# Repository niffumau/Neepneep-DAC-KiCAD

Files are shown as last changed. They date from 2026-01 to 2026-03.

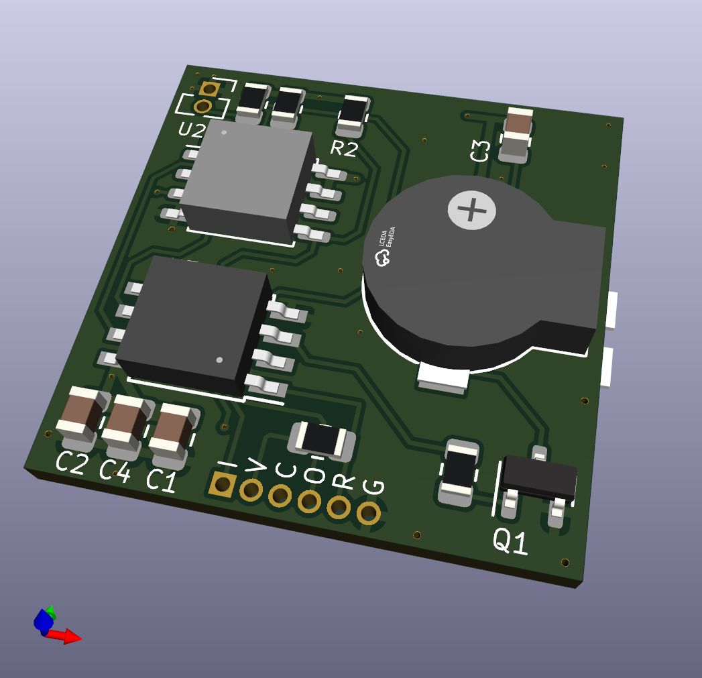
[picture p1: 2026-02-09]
V2/NeepNeep-DAC-V2.png

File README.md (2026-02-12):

# Neepneep DAC

This is the version that plays audio from a flash chip.

## V1
My original prototype, working with the Attiny85 and the winbond W25Q32 flash chip.

## V2

V2 is currently a work in progress, i'm trying bring the cost down so i'm trying to switch over to a smaller flash and move over to a different chip so this one will not program the Attiny85

I'm looking at the Attiny412 and the 8mbit version of the flash chip.

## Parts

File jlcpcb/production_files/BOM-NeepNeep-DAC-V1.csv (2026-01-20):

Comment | Designator | Footprint | LCSC
W25Q32JVSS | U2 | SOIC-8_5.23x5.23mm_P1.27mm | C179173
MMBT3904 | Q1 | SOT-23 | C20526
ATtiny85-20SU | U3 | SOIC-8W_5.3x5.3mm_P1.27mm | C31540447
YS-SBZ9032C03R16_C409828 | BUZZER1 | BUZ-SMD_FUET-9025-XXV | C409828
100nF | C4 | C_0805_2012Metric
100nF | C3 | C_0805_2012Metric
10k | R3 | R_0805_2012Metric
10k | R2 | R_0805_2012Metric
10k | R1 | R_0805_2012Metric
1N4148W | D3 | D_SOD-123
1N4148W | D2 | D_SOD-123
1N4148W | D1 | D_SOD-123
47uF | C1 | C_0805_2012Metric
10K | R6 | R_0805_2012Metric
100nF | C2 | C_0805_2012Metric
1k | R7 | R_0805_2012Metric

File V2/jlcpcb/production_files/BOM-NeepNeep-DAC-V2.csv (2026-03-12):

Comment | Designator | Footprint | LCSC
W25Q32JVSS | U2 | SOIC-8_5.23x5.23mm_P1.27mm | C179173
YS-SBZ9032C03R16_C409828 | BUZZER1 | BUZ-SMD_FUET-9025-XXV | C409828
Battery | BT1 | BatteryHolder_SMD_TAB_2032 | C964835
Conn_02x03_Odd_Even | J1 | SPI-Header_1x06_P1.27mm
Conn_01x03_Pin | J2 | UPDI PinHeader_1x03_P1.27mm_Vertical
47uF | C1 | C_0805_2012Metric
100k | R4 | R_0805_2012Metric
BSS138 | Q1 | SOT-23
10K | R6 | R_0805_2012Metric
10k | R3 | R_0805_2012Metric
10k | R2 | R_0805_2012Metric
100nF | C3 | C_0805_2012Metric
10k | R1 | R_0805_2012Metric
100nF | C4 | C_0805_2012Metric
100nF | C2 | C_0805_2012Metric
1k | R7 | R_0805_2012Metric
ATtiny412-SS | U1 | SOIC-8_3.9x4.9mm_P1.27mm

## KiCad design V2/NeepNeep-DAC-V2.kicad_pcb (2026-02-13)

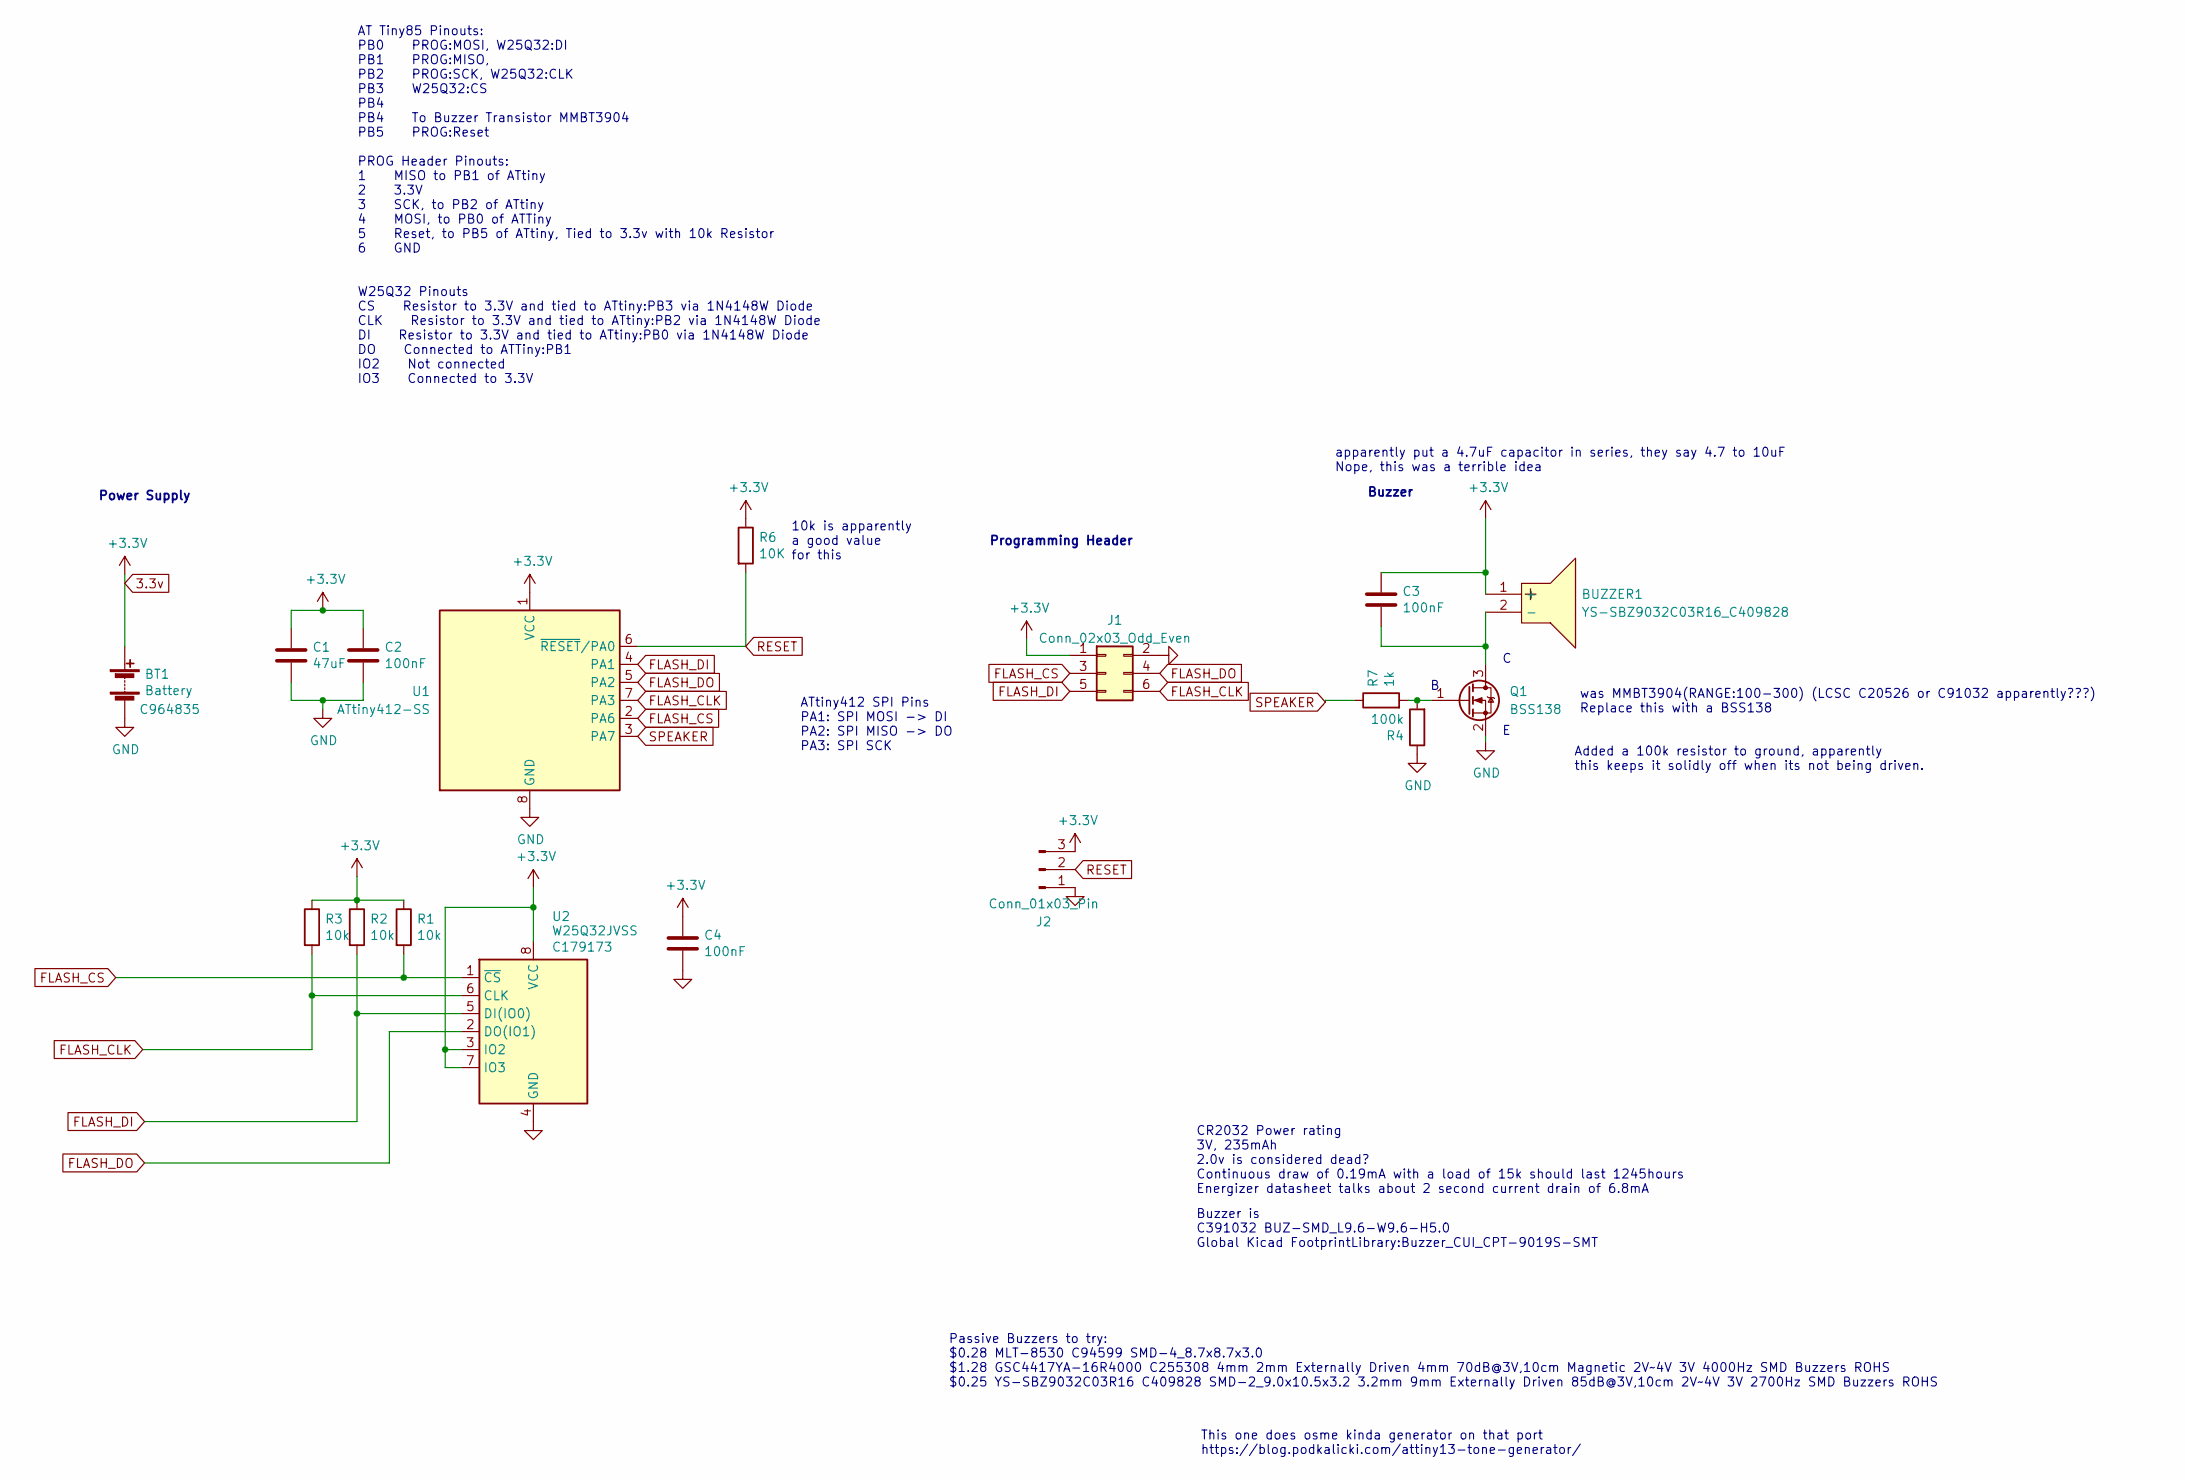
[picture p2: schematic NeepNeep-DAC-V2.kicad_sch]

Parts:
BT1: Battery; BatteryHolder_SMD_TAB_2032; LCSC C964835
BUZZER1: YS-SBZ9032C03R16_C409828; BUZ-SMD_FUET-9025-XXV; LCSC Part C409828
C1: 47uF; C_0805_2012Metric
C2, C3, C4: 100nF; C_0805_2012Metric
J1: Conn_02x03_Odd_Even; SPI-Header_1x06_P1.27mm
J2: Conn_01x03_Pin; UPDI PinHeader_1x03_P1.27mm_Vertical
Q1: BSS138; SOT-23
R1, R2, R3: 10k; R_0805_2012Metric
R4: 100k; R_0805_2012Metric
R6: 10K; R_0805_2012Metric
R7: 1k; R_0805_2012Metric
U1: ATtiny412-SS; SOIC-8_3.9x4.9mm_P1.27mm
U2: W25Q32JVSS; SOIC-8_5.23x5.23mm_P1.27mm; LCSC C179173

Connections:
3.3v: BT1.1 (+), BUZZER1.1 (+), C1.1, C2.1, C3.1, C4.1, J1.1, J2.3, R1.1, R2.1, R3.1, R6.1, U1.1 (VCC), U2.3 (IO2), U2.7 (IO3), U2.8 (VCC)
FLASH_CLK: J1.6, R3.2, U1.7 (PA3), U2.6 (CLK)
FLASH_CS: J1.3, R1.2, U1.2 (PA6), U2.1 (~CS)
FLASH_DI: J1.5, R2.2, U1.4 (PA1), U2.5 (DI(IO0))
FLASH_DO: J1.4, U1.5 (PA2), U2.2 (DO(IO1))
GND: BT1.2 (-), C1.2, C2.2, C4.2, J1.2, J2.1, Q1.2 (S), R4.1, U1.8 (GND), U2.4 (GND)
unnamed: BUZZER1.2 (-), C3.2, Q1.3 (D)
unnamed: Q1.1 (G), R4.2, R7.2
RESET: J2.2, R6.2, U1.6 (~RESET/PA0)
SPEAKER: R7.1, U1.3 (PA7)

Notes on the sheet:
apparently put a 4.7uF capacitor in series, they say 4.7 to 10uF Nope, this was a terrible idea
This one does osme kinda generator on that port https://blog.podkalicki.com/attiny13-tone-generator/
Programming Header
ATtiny412 SPI Pins PA1: SPI MOSI -> DI PA2: SPI MISO -> DO PA3: SPI SCK
Buzzer is C391032 BUZ-SMD_L9.6-W9.6-H5.0 Global Kicad FootprintLibrary:Buzzer_CUI_CPT-9019S-SMT
Added a 100k resistor to ground, apparently this keeps it solidly off when its not being driven.
Buzzer
AT Tiny85 Pinouts: PB0 PROG:MOSI, W25Q32:DI PB1 PROG:MISO, PB2 PROG:SCK, W25Q32:CLK PB3 W25Q32:CS PB4 PB4 To Buzzer Transistor MMBT3904 PB5 PROG:Reset PROG Header Pinouts: 1 MISO to PB1 of ATtiny 2 3.3V 3 SCK, to PB2 of ATtiny 4 MOSI, to PB0 of ATTiny 5 Reset, to PB5 of ATtiny, Tied to 3.3v with 10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
CR2032 Power rating 3V, 235mAh 2.0v is considered dead? Continuous draw of 0.19mA with a load of 15k should last 1245hours Energizer datasheet talks about 2 second current drain of 6.8mA
Passive Buzzers to try: $0.28 MLT-8530 C94599 SMD-4_8.7x8.7x3.0 $1.28 GSC4417YA-16R4000 C255308 4mm 2mm Externally Driven 4mm 70dB@3V,10cm Magnetic 2V~4V 3V 4000Hz SMD Buzzers ROHS $0.25 YS-SBZ9032C03R16 C409828 SMD-2_9.0x10.5x3.2 3.2mm 9mm Externally Driven 85dB@3V,10cm 2V~4V 3V 2700Hz SMD Buzzers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
Power Supply
10k is apparently a good value for this
was MMBT3904(RANGE:100-300) (LCSC C20526 or C91032 apparently???) Replace this with a BSS138

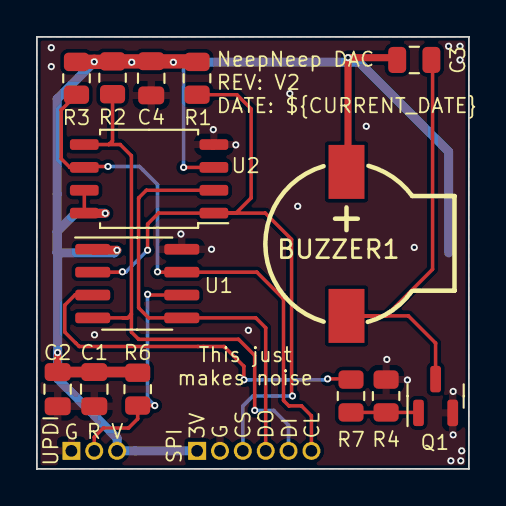
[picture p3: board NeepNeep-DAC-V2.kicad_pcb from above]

Board: 2 copper layers, 24.0 x 24.0 mm, 17 parts (1 on the bottom side), 10 nets.

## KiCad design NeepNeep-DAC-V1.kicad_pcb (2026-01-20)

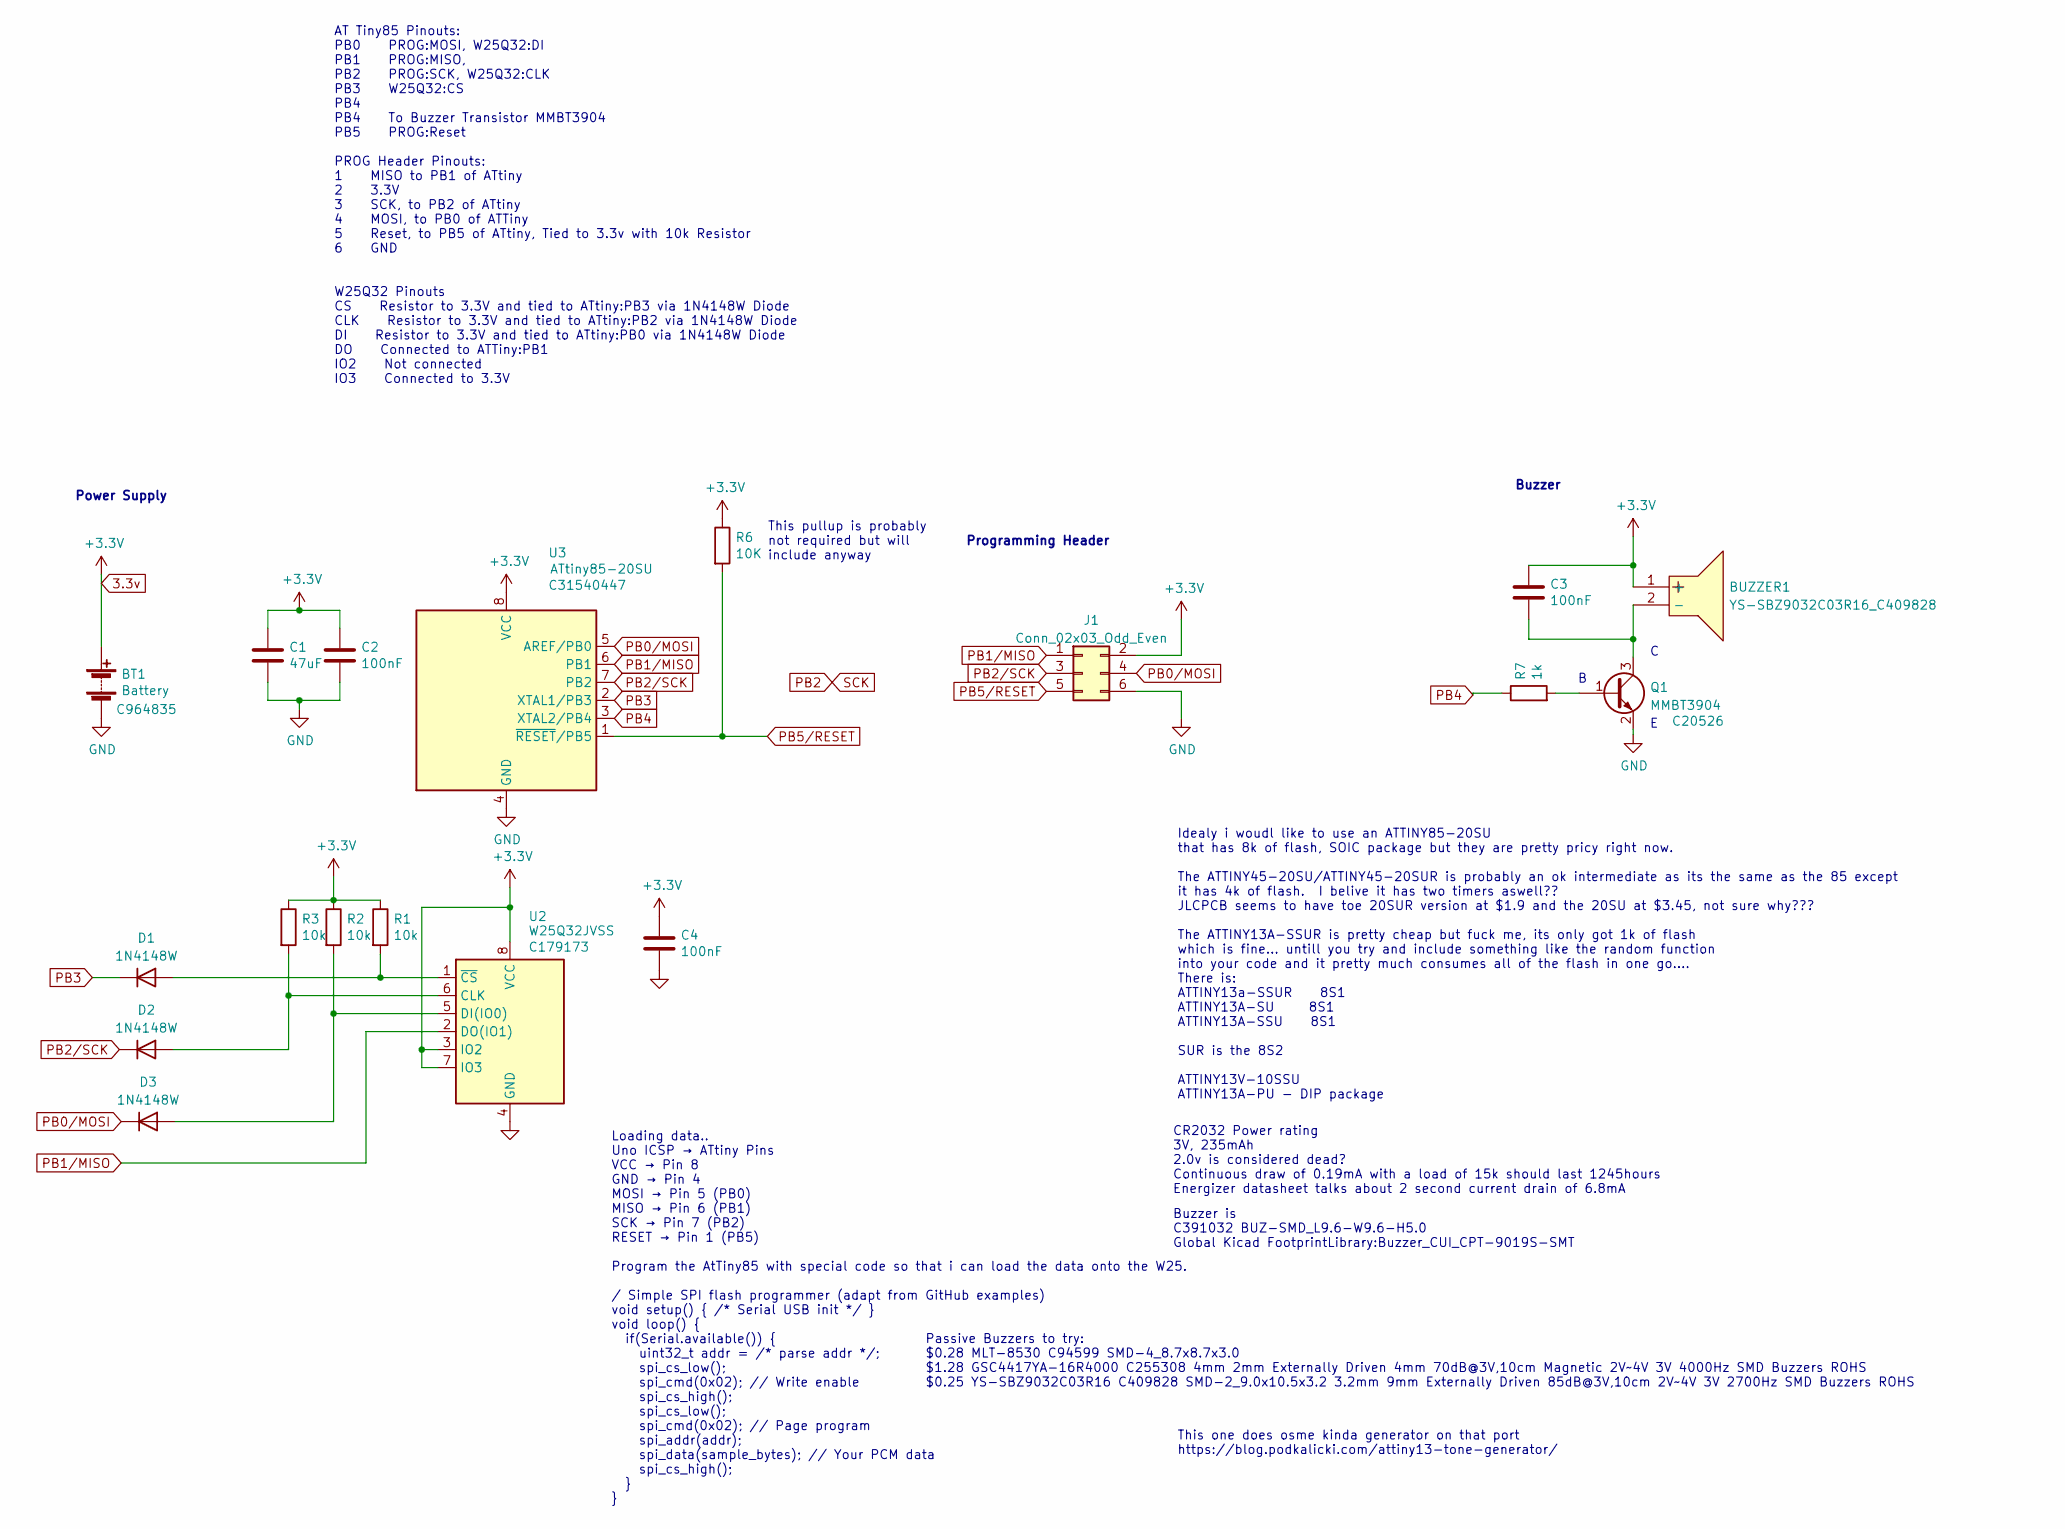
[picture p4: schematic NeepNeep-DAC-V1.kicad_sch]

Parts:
BT1: Battery; BatteryHolder_SMD_TAB_2032; LCSC C964835
BUZZER1: YS-SBZ9032C03R16_C409828; BUZ-SMD_FUET-9025-XXV; LCSC Part C409828
C1: 47uF; C_0805_2012Metric
C2, C3, C4: 100nF; C_0805_2012Metric
D1, D2, D3: 1N4148W; D_SOD-123
J1: Conn_02x03_Odd_Even; PRG-Header_1x06_P1.27mm
Q1: MMBT3904; SOT-23; LCSC C20526
R1, R2, R3: 10k; R_0805_2012Metric
R6: 10K; R_0805_2012Metric
R7: 1k; R_0805_2012Metric
U2: W25Q32JVSS; SOIC-8_5.23x5.23mm_P1.27mm; LCSC C179173
U3: ATtiny85-20SU; SOIC-8W_5.3x5.3mm_P1.27mm; LCSC C31540447

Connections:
3.3v: BT1.1 (+), BUZZER1.1 (+), C1.1, C2.1, C3.1, C4.1, J1.2, R1.1, R2.1, R3.1, R6.1, U2.3 (IO2), U2.7 (IO3), U2.8 (VCC), U3.8 (VCC)
GND: BT1.2 (-), C1.2, C2.2, C4.2, J1.6, Q1.2 (E), U2.4 (GND), U3.4 (GND)
unnamed: BUZZER1.2 (-), C3.2, Q1.3 (C)
unnamed: D1.2 (A), R1.2, U2.1 (~CS)
unnamed: D2.2 (A), R3.2, U2.6 (CLK)
unnamed: D3.2 (A), R2.2, U2.5 (DI(IO0))
unnamed: Q1.1 (B), R7.2
PB0/MOSI: D3.1 (K), J1.4, U3.5 (AREF/PB0)
PB1/MISO: J1.1, U2.2 (DO(IO1)), U3.6 (PB1)
PB2/SCK: D2.1 (K), J1.3, U3.7 (PB2)
PB3: D1.1 (K), U3.2 (XTAL1/PB3)
PB4: R7.1, U3.3 (XTAL2/PB4)
PB5/RESET: J1.5, R6.2, U3.1 (~RESET/PB5)

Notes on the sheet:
This one does osme kinda generator on that port https://blog.podkalicki.com/attiny13-tone-generator/
Programming Header
Buzzer is C391032 BUZ-SMD_L9.6-W9.6-H5.0 Global Kicad FootprintLibrary:Buzzer_CUI_CPT-9019S-SMT
Idealy i woudl like to use an ATTINY85-20SU that has 8k of flash, SOIC package but they are pretty pricy right now. The ATTINY45-20SU/ATTINY45-20SUR is probably an ok intermediate as its the same as the 85 except it has 4k of flash. I belive it has two timers aswell?? JLCPCB seems to have toe 20SUR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
Buzzer
Loading data.. Uno ICSP → ATtiny Pins VCC → Pin 8 GND → Pin 4 MOSI → Pin 5 (PB0) MISO → Pin 6 (PB1) SCK → Pin 7 (PB2) RESET → Pin 1 (PB5) Program the AtTiny85 with special code so that i can load the data onto the W25. / Simple SPI flash programmer (adapt from GitHub examples) void setup() { /* Ser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
AT Tiny85 Pinouts: PB0 PROG:MOSI, W25Q32:DI PB1 PROG:MISO, PB2 PROG:SCK, W25Q32:CLK PB3 W25Q32:CS PB4 PB4 To Buzzer Transistor MMBT3904 PB5 PROG:Reset PROG Header Pinouts: 1 MISO to PB1 of ATtiny 2 3.3V 3 SCK, to PB2 of ATtiny 4 MOSI, to PB0 of ATTiny 5 Reset, to PB5 of ATtiny, Tied to 3.3v with 10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
CR2032 Power rating 3V, 235mAh 2.0v is considered dead? Continuous draw of 0.19mA with a load of 15k should last 1245hours Energizer datasheet talks about 2 second current drain of 6.8mA
Passive Buzzers to try: $0.28 MLT-8530 C94599 SMD-4_8.7x8.7x3.0 $1.28 GSC4417YA-16R4000 C255308 4mm 2mm Externally Driven 4mm 70dB@3V,10cm Magnetic 2V~4V 3V 4000Hz SMD Buzzers ROHS $0.25 YS-SBZ9032C03R16 C409828 SMD-2_9.0x10.5x3.2 3.2mm 9mm Externally Driven 85dB@3V,10cm 2V~4V 3V 2700Hz SMD Buzzers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
Power Supply
This pullup is probably not required but will include anyway

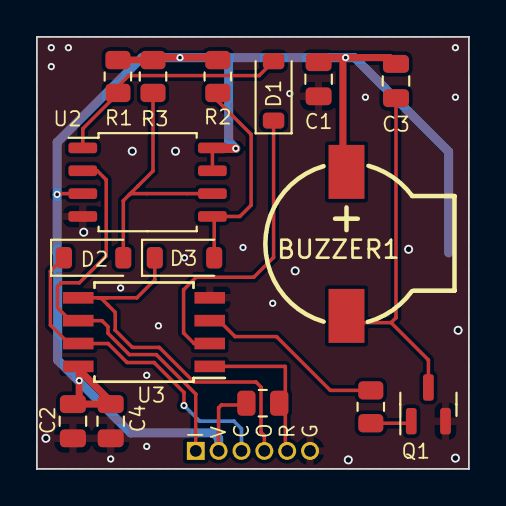
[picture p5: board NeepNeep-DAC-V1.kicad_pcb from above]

Board: 2 copper layers, 24.0 x 24.0 mm, 18 parts (1 on the bottom side), 13 nets.

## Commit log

2026-01-20 Commit: A .gitignore A NeepNeep-DAC-V1.kicad_pcb A NeepNeep-DAC-V1.kicad_prl A NeepNeep-DAC-V1.kicad_pro A NeepNeep-DAC-V1.kicad_sch A bom/ibom.html A fp-info-cache A jlcpcb/gerber/NeepNeep-DAC-V1-Cu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
    [BOM-NeepNeep-DAC-V1.csv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]
2026-02-05 Commit: M NeepNeep-DAC-V1.kicad_sch
    [NeepNeep-DAC-V1.kicad_sch]
2026-02-05 Commit: M NeepNeep-DAC-V1.kicad_sch A V2/NeepNeep-DAC-V2-backups/NeepNeep-DAC-V2-2026-02-05_161125.zip A V2/NeepNeep-DAC-V2-backups/NeepNeep-DAC-V2-2026-02-05_170153.zip A V2/NeepNeep-DAC-V2.kicad_pc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
    [NeepNeep-DAC-V2.kicad_pcb, NeepNeep-DAC-V2.kicad_sch]
2026-02-09 Commit: A V2/NeepNeep-DAC-V2-backups/NeepNeep-DAC-V2-2026-02-06_155723.zip A V2/NeepNeep-DAC-V2-backups/NeepNeep-DAC-V2-2026-02-06_161052.zip A V2/NeepNeep-DAC-V2-backups/NeepNeep-DAC-V2-2026-02-06_1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
    [NeepNeep-DAC-V2.kicad_pcb]
2026-02-11 Commit: A V2/NeepNeep-DAC-V2-backups/NeepNeep-DAC-V2-2026-02-09_174934.zip A V2/NeepNeep-DAC-V2-backups/NeepNeep-DAC-V2-2026-02-10_125359.zip A V2/NeepNeep-DAC-V2-backups/NeepNeep-DAC-V2-2026-02-10_1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
    [NeepNeep-DAC-V2.kicad_pcb, NeepNeep-DAC-V2.kicad_sch]
2026-02-11 Commit: A V2/NeepNeep-DAC-V2-backups/NeepNeep-DAC-V2-2026-02-11_154859.zip A V2/NeepNeep-DAC-V2-backups/NeepNeep-DAC-V2-2026-02-11_164151.zip A V2/NeepNeep-DAC-V2-backups/NeepNeep-DAC-V2-2026-02-11_1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
    [NeepNeep-DAC-V2.kicad_pcb, NeepNeep-DAC-V2.kicad_sch]
2026-02-12 Commit: M README.md A V2/NeepNeep-DAC-V2-backups/NeepNeep-DAC-V2-2026-02-12_124743.zip A V2/NeepNeep-DAC-V2-backups/NeepNeep-DAC-V2-2026-02-12_132550.zip A V2/NeepNeep-DAC-V2-backups/NeepNeep-DAC-V2-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
    [BOM-NeepNeep-DAC-V2.csv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]
2026-02-13 Commit: D V2/NeepNeep-DAC-V2-backups/NeepNeep-DAC-V2-2026-02-12_132550.zip A V2/NeepNeep-DAC-V2-backups/NeepNeep-DAC-V2-2026-02-13_132614.zip A V2/NeepNeep-DAC-V2-backups/NeepNeep-DAC-V2-2026-02-13_1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
    [NeepNeep-DAC-V2.kicad_pcb, NeepNeep-DAC-V2.kicad_sch]
2026-02-13 Commit: D V2/NeepNeep-DAC-V2-backups/NeepNeep-DAC-V2-2026-02-13_132614.zip D V2/NeepNeep-DAC-V2-backups/NeepNeep-DAC-V2-2026-02-13_133905.zip D V2/NeepNeep-DAC-V2-backups/NeepNeep-DAC-V2-2026-02-13_1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
    [NeepNeep-DAC-V2.kicad_pcb]
2026-03-12 Commit: D V2/NeepNeep-DAC-V2-backups/NeepNeep-DAC-V2-2026-02-13_141833.zip A V2/NeepNeep-DAC-V2-backups/NeepNeep-DAC-V2-2026-02-16_160315.zip A V2/NeepNeep-DAC-V2-backups/NeepNeep-DAC-V2-2026-03-12_1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
    [BOM-NeepNeep-DAC-V2.csv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]
